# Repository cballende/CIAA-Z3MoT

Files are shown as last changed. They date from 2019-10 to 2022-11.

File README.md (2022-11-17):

# CIAA-Z3MoT
Simplificación de base board Silabs subGHz :
EZR32 Happy gecko board for QFP48 parts (EZR32HG)
[SLWSTK6244A](https://www.silabs.com/products/development-tools/wireless/proprietary/slwstk6244a-ezr32-happy-gecko-169-mhz-starter-kit)

| Kit | Frequency(MHz)| Output Power(dBm) |Included Device |
| --- |:---:| -----:|-----:|
| SLWSTK6244A | 169 | +20 | ZR32HG330FG63G |

#### Caracteristicas

* Adaptación de [CIAA-Z3R0](http://www.proyecto-ciaa.com.ar/devwiki/doku.php?id=desarrollo:ciaa-z3r0) hacia un enfoque de [MoTe](https://en.wikipedia.org/wiki/Sensor_node).

* Los pines entre Z3R0 y Z3MoT són compatibles en cierto grado, con excepción de los destinados a la interface RF.

* Puertos y pines deprecados de la versión Z3RO a la Z3MoT:
  - A:2,8,9,10. 
  - C:0,1,2,3,4. 

* Introduce 4 GPIO: 
Se utilizan 3 lineas para configurar puerto I2C para memoria EEPROM y posibles MEMs(disponibles V2.0,temperatura,humedad,7DOF,Altímetro-barómetro,luxómetro)

Deja un GPIO libre configurable sobre los restantes puertos:
- A:0,1.
- B:7,8,11,13,14.
- C:8,9,10,14,15.
- D:4,5,6,7.
- E:10,11,12,13.
- F:0,1,2,3,4.

* USB:
El conector usb se modifico, no se utiliza conector soldable. Se implemento un plug en pcb USB A troquelable, brindando la posiblidad soldar tira de pines de paso 1,27" o soldar en PCB tipo castellated.

* Alimentación:
Selección mediante jumper permitiendo conmutar bateria o (USB / PCBtarget).
La alimentación mediante bateria se implemento con fuente DC/DC tipo boost.

* Autonomía:
El stick Z3MoT tiene la posiblidad de usar baterias tipo boton CR2032(3V)(1,8 años autonomia 225 mAh) o mediante Pila AAA(7,25 años 1,5V de 900-1155 mAh). 

* Conectores RF:
Es posible utilizar dos tipos de conectores uno SMD(por defecto) y otro SMA(soldando via).

* JTAG:
Los pines utilizados en Z3RO son los mismos que para Z3MoT. Se adiciona tira de pines para conexión ordenada de JTAG  mediante sondas con resortes montadas sobre una pinza o base con balancin.
 

#### Schematic

[Schematic in pdf](ciaa-z3mot.pdf)
board schematic

#### 3D view

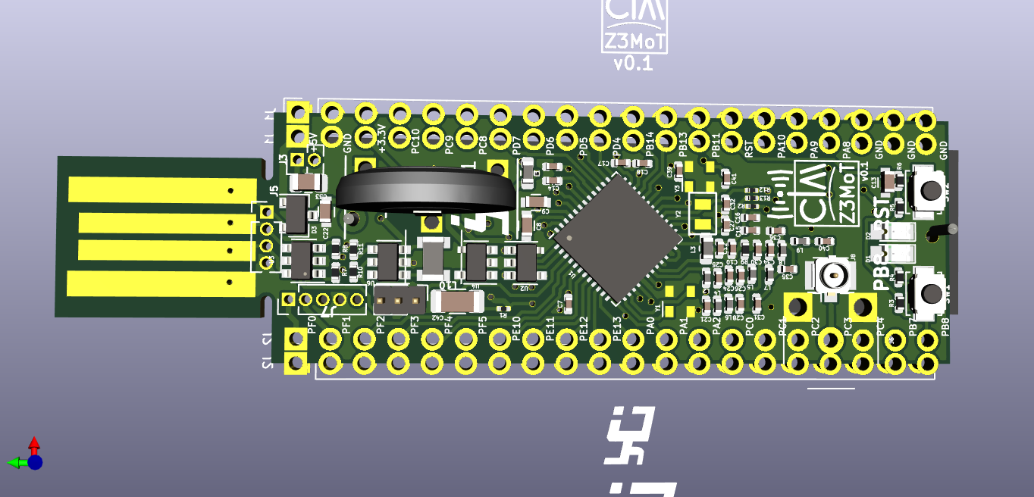
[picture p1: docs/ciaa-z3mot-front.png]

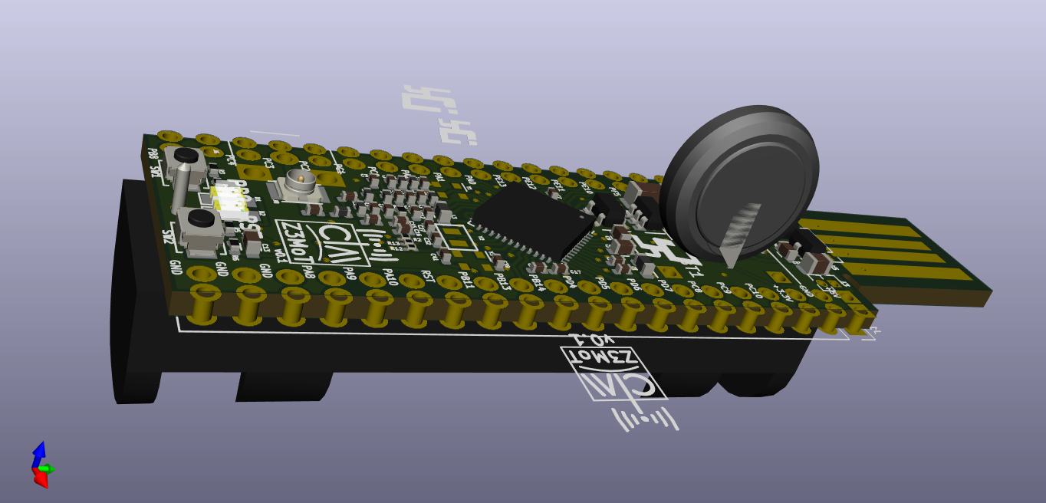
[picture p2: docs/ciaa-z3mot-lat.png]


## Vista con opciones de bateria y conector RF

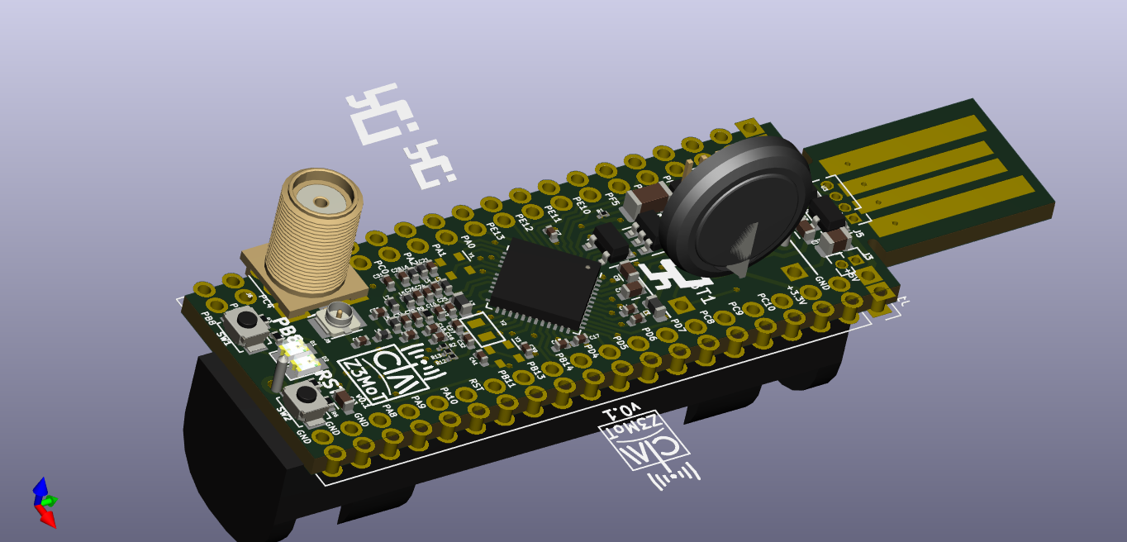
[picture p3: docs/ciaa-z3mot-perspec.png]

## Video (YOUTUBE)
Watch the video (https://youtu.be/JIxqX9fWDKY "Video CIAA-Z3MoT")

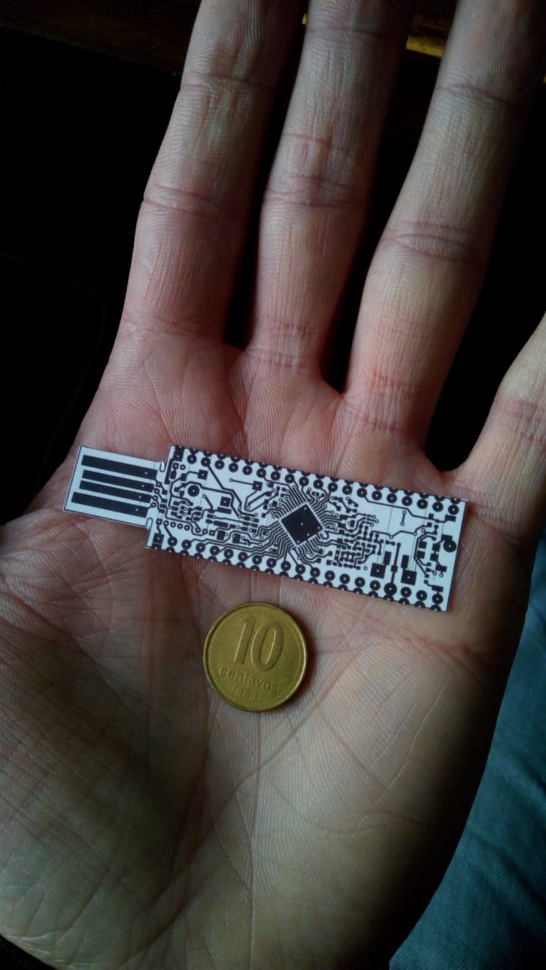
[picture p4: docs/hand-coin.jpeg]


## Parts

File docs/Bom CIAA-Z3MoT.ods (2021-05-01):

REFERENCIA | Qty. | Qty 100 | Qty 1000 | Qty 10000 | VALOR | HUELLA | DESCRIPCION | PART | digikey part number | ARROW | MOUSER | Pricing
BT1 | 1 | 100 | 1000 | 10000 | Battery_Cell | Battery holder CR2032-VS1N_Vertical_CircularHoles |  |  | 1
 |  | 0 | 0 | 0
C7 | 1 | 100 | 1000 | 10000 | 100n | Capacitor_SMD:C_0402_1005Metric |  | CC0402KRX7R7BB104 | 311-1088-1-ND |  | 603-CC603KRX7R7BB104
C8 | 1 | 100 | 1000 | 10000 | 1u | Capacitor_SMD:C_0603_1608Metric | Taiyo Yuden / Samsung | JMK107B7105KA-T / CL10B105KQ8NNNC | 1276-1024-1-ND |  | 963-JMK107B7105KA-T
C9 | 1 | 100 | 1000 | 10000 | 4,7u | Capacitor_SMD:C_0603_1608Metric | Taiyo Yuden | JMK107BB7475KA-T | 587-5870-1-ND |  | 963-JMK107BB7475KA-T
C10 | 1 | 100 | 1000 | 10000 | 100p | Capacitor_SMD:C_0402_1005Metric |  | CC0402JRNPO8BN101 | 311-3597-1-ND |  | 603-CC402JRNPO8BN101
C11 | 1 | 100 | 1000 | 10000 | 100n | Capacitor_SMD:C_0402_1005Metric |  | CC0402KRX7R7BB104 | 311-1088-1-ND |  | 603-CC603KRX7R7BB104
C12 | 1 | 100 | 1000 | 10000 | 470p | Capacitor_SMD:C_0402_1005Metric |  | CC0402JRNPO7BN471 | 311-1362-1-ND |  | 603-CC402JRNPO7BN471
C13 | 1 | 100 | 1000 | 10000 | 1u | Capacitor_SMD:C_0603_1608Metric |  | JMK107B7105KA-T | 311-1446-1-ND |  | 603-CC603KRX7R7BB105
C14 | 1 | 100 | 1000 | 10000 | 1u | Capacitor_SMD:C_0603_1608Metric | Taiyo Yuden / Samsung | JMK107B7105KA-T / CL10B105KQ8NNNC | 1276-1024-1-ND |  | 963-JMK107B7105KA-T
C15 | 1 | 100 | 1000 | 10000 | 100n | Capacitor_SMD:C_0402_1005Metric |  | CC0402KRX7R7BB104 | 311-1088-1-ND |  | 603-CC603KRX7R7BB104
C16 | 1 | 100 | 1000 | 10000 | 1u | Capacitor_SMD:C_0603_1608Metric | Taiyo Yuden / Samsung | JMK107B7105KA-T / CL10B105KQ8NNNC | 1276-1024-1-ND |  | 963-JMK107B7105KA-T
C17 | 1 | 100 | 1000 | 10000 | 100n | Capacitor_SMD:C_0402_1005Metric |  | CC0402KRX7R7BB104 | 311-1088-1-ND |  | 603-CC603KRX7R7BB104
C18 | 1 | 100 | 1000 | 10000 | 100n | Capacitor_SMD:C_0402_1005Metric |  | CC0402KRX7R7BB104 | 311-1088-1-ND |  | 603-CC603KRX7R7BB104
C42 | 1 | 100 | 1000 | 10000 | 10u | Capacitor_SMD:C_1206_3216Metric | Taiyo Yuden | JMK316BJ106KL-T | 587-5873-1-ND |  | 963-JMK316BJ106KL-T
C21 | 1 | 100 | 1000 | 10000 | 12p | Capacitor_SMD:C_0402_1005Metric |  | CC0402JRNPO9BN120 | 311-1016-1-ND |  | 603-CC402JRNPO9BN120
C22 | 1 | 100 | 1000 | 10000 | 1u | Capacitor_SMD:C_0603_1608Metric | Taiyo Yuden / Samsung | JMK107B7105KA-T / CL10B105KQ8NNNC | 1276-1024-1-ND |  | 963-JMK107B7105KA-T
C24 | 1 | 100 | 1000 | 10000 | 470p | Capacitor_SMD:C_0402_1005Metric |  | CC0402JRNPO7BN471 | 311-1362-1-ND |  | 603-CC402JRNPO7BN471
C25 | 1 | 100 | 1000 | 10000 | 6,2p | Capacitor_SMD:C_0402_1005Metric | KEMET | CBR04C629B5GAC | 399-16105-1-ND |  | 80-CBR04C629B5G
C26 | 1 | 100 | 1000 | 10000 | 11p | Capacitor_SMD:C_0402_1005Metric | KEMET | CBR04C110J5GAC | 399-8818-1-ND |  | 603-CC603KRX7R7BB104
C36 | 1 | 100 | 1000 | 10000 | 12p | Capacitor_SMD:C_0402_1005Metric |  | CBR04C120J5GAC | 399-6169-1-ND
C28 | 1 | 100 | 1000 | 10000 | NM | Capacitor_SMD:C_0402_1005Metric
C30 | 1 | 100 | 1000 | 10000 | 18p | Capacitor_SMD:C_0402_1005Metric | Yageo | CC0402JRNPO9BN180 | 311-1415-1-ND |  | 603-CC402JRNPO9BN180
C31 | 1 | 100 | 1000 | 10000 | 3p | Capacitor_SMD:C_0402_1005Metric | Yageo | CC0402CRNPO9BN3R0 | 311-1007-2-ND |  | 603-CC402CRNPO9BN3R0
C32 | 1 | 100 | 1000 | 10000 | 12p | Capacitor_SMD:C_0402_1005Metric |  | CBR04C120J5GAC | 399-6169-1-ND
C33 | 1 | 100 | 1000 | 10000 | 4,7u | Capacitor_SMD:C_0805_Metric | Walsin | 0805B475K6R3CT |  |  | 791-0805B475K6R3CT
C34 | 1 | 100 | 1000 | 10000 | 18p | Capacitor_SMD:C_0402_1005Metric | Yageo | CC0402JRNPO9BN180 | 311-1415-1-ND |  | 603-CC402JRNPO9BN180
C35 | 1 | 100 | 1000 | 10000 | 2p | Capacitor_SMD:C_0402_1005Metric | Yageo | CC0402CRNPO9BN2R0 | 311-1006-1-ND |  | 603-CC402CRNPO9BN2R0
C36 | 1 | 100 | 1000 | 10000 | 11p | Capacitor_SMD:C_0402_1005Metric | Samsung | CL05C110JB5NNNC | 1276-1637-1-ND | CL05C110JB5NNNC
C39 | 1 | 100 | 1000 | 10000 | 10p | Capacitor_SMD:C_0402_1005Metric |  | CBR04C100J5GAC | 399-6168-1-ND
C40 | 1 | 100 | 1000 | 10000 | 470p | Capacitor_SMD:C_0402_1005Metric |  | CC0402JRNPO7BN471 | 311-1362-1-ND |  | 603-CC402JRNPO7BN471
C41 | 1 | 100 | 1000 | 10000 | 10p | Capacitor_SMD:C_0402_1005Metric |  | CBR04C100J5GAC | 399-6168-1-ND
 |  | 0 | 0 | 0
D1 | 1 | 100 | 1000 | 10000 | PA8 | LED_0805 |  | LTST-C170GKT | 160-1179-1-ND
D2 | 1 | 100 | 1000 | 10000 | PWR | LED_0805 |  | LTST-C170GKT | 160-1179-1-ND
D3 | 1 | 100 | 1000 | 10000 | PMEG2005CT | SOT-23-3 |  | PMEG2005CT,215 | 1727-5188-1-ND
 |  | 0 | 0 | 0
J1, J2 |  | 0 | 0 | 0 | NM
J3 | 1 | 100 | 1000 | 10000 | JTAG | PinHeader_1x05_P1.27mm_Vertical
J4 | 1 | 100 | 1000 | 10000 | ON | PinHeader_1x02_P1.27mm_Vertical
J5 | 1 | 100 | 1000 | 10000 | SWD | PinHeader_1x03_P1.27mm_Vertical
J6 | 1 | 100 | 1000 | 10000 | USB | PinHeader_1x04_P1.27mm_Vertical
J7 | 1 | 100 | 1000 | 10000 | Conn_Coaxial | Connector_Coaxial:U.FL_Hirose_U.FL-R-SMT-1_Vertical |  | IPX U.FL RF
J8 | 1 | 100 | 1000 | 10000 | Conn_Coaxial | Connector_Coaxial:SMA_Amphenol_132134-16_Vertical
 |  | 0 | 0 | 0
L1 | 1 | 100 | 1000 | 10000 | Choque | Inductor_SMD:L_0402_1005Metric | Murata Electronics | BLM15AG121SN1D | 490-1005-1-ND |  | 81-BLM15AG121SN1D
L2 | 1 | 100 | 1000 | 10000 | 220 nH | Inductor_SMD:L_0402_1005Metric | Murata Electronics | LQW15CNR22J10D | 490-14717-1-ND |  | 81-LQW15CNR22J10D
L3 | 1 | 100 | 1000 | 10000 | 390 nH | Inductor_SMD:L_0603_1608Metric | Würth Elektronik | 744761239A | 732-744761239ACT-ND |  | 710-744761239A
L4 | 1 | 100 | 1000 | 10000 | 160nH | Inductor_SMD:L_0402_1005Metric | Murata Electronics | LQW15CNR16J00D | 490-14716-1-ND |  | 81-LQW15CNR16J00D0D
L5 | 1 | 100 | 1000 | 10000 | 82nH | Inductor_SMD:L_0402_1005Metric | Murata Electronics | LQW15AW82NJ80D |  |  | 81-LQW15AW82NJ80D
L6 | 1 | 100 | 1000 | 10000 | 47nH | Inductor_SMD:L_0402_1005Metric | Murata Electronics | LQW15AN47NJ80D |  |  | 81-LQW15AN47NJ80D
L8 | 1 | 100 | 1000 | 10000 | 47nH | Inductor_SMD:L_0402_1005Metric | Murata Electronics | LQW15AN47NJ80D |  |  | 81-LQW15AN47NJ80D
L7 | 1 | 100 | 1000 | 10000 | 68nH | Inductor_SMD:L_0402_1005Metric | Murata Electronics | LQW15AW68NJ80D |  |  | 81-LQW15AW68NJ80D
L9 | 1 | 100 | 1000 | 10000 | 27nH | Inductor_SMD:L_0402_1005Metric | Murata Electronics | LQW15AN27NJ8ZD | 490-15374-1-ND |  | 81-LQW15AN27NJ8ZD
L10 | 1 | 100 | 1000 | 10000 | 4,7uH | Inductor_SMD:L_-1008 (2520 Metric) | Murata Electronics | LQH2HPN4R7MJRL | 490-9904-1-ND |  | 81-LQH2HPN4R7MJRL
 |  | 0 | 0 | 0
R1, R2, | 2 | 200 | 2000 | 20000 | 1R | Resistor_SMD:R_0201_0603Metric | yageo | RC0201JR-071RL |  |  | 603-RC0201JR-071RL
R12-R13 | 2 | 200 | 2000 | 20000 | 0R | Resistor_SMD:R_0201_0603Metric | Vishay / Dale | CRCW02010000Z0ED | P15979CT-ND |  | 71-CRCW02010000Z0ED
R3-R4-R5-R6 | 4 | 400 | 4000 | 40000 | 1K | Resistor_SMD:R_0402_1005Metric | yageo | RC0402JR-071KL | 311-1.0KJRTR-ND
R7, R8 | 2 | 200 | 2000 | 20000 | 15R | Resistor_SMD:R_0402_1005Metric | yageo | RC0402JR-0715RL | 311-15JRCT-ND
R9 | 1 | 100 | 1000 | 10000 | 50 | Resistor_SMD:R_0402_1005Metric | yageo | RC0402FR-0749R9L | 311-49.9LRCT-ND
R11 | 1 | 100 | 1000 | 10000 | 562K | Resistor_SMD:R_0402_1005Metric | yageo | RC0402FR-07562KL | 311-562KLRCT-ND
R10 | 1 | 100 | 1000 | 10000 | 976K | Resistor_SMD:R_0402_1005Metric | yageo | RC0402FR-07976KL | YAG3265CT-ND
> SW1, SW2 | 2 | 200 | 2000 | 20000 | reset | Button_Switch_SMD: B3U-1000P 1.70 X 3 X2.5 mm |  | B3U-1000P
 |  | 0 | 0 | 0
U1 | 1 | 100 | 1000 | 10000 | EZM32HG320-48QFN | QFN-48-1EP_7x7mm_P0.5mm_EP5.3x5.3mm | Silabs | EZR32HG320F64R68G | 336-3677-ND | EZR32HG320F64R68G-B0 | EZR32HG320F64R68G-B0 | $4.60
U2 | 1 | 100 | 1000 | 10000 | 24AA02E48-OT | SOT-23-5 |  | 24AA02E48T-I/OT | 24AA02E48T-I/OTCT-ND
U3 | 1 | 100 | 1000 | 10000 | USBLC6-2 | SOT-23-6 |  | USBLC6-2SC6 | 497-5235-1-ND
U4 | 1 | 100 | 1000 | 10000 | SPX3819M5-L-3-3 | SOT-23-5 |  | SPX3819M5-L-3-3/TR | 1016-1873-1-ND
U5 | 1 | 100 | 1000 | 10000 | USB_PCB_PRINT | USB_PCB_FOOTPRINT
U6 | 1 | 100 | 1000 | 10000 | MCP1640C | SOT-23-6 | MICROCHIP | MCP1640CT-I/CHY | MCP1640CT-I/CHYCT-ND
 |  | 0 | 0 | 0
Y1 | 1 | 100 | 1000 | 10000 | 30MHz | Oscillator:Oscillator_SMD_Abracon_ASDMB-4Pin_2x1,6mm | Abracon LLC | ABM11-30.000MHZ-B1U-T | 535-14960-1-ND
Y2 | 1 | 100 | 1000 | 10000 | 32.1KHz | footprints:Xtal_LF | Abracon LLC | ABS06-32.768KHZ-1-T | 535-10248-1-ND |  | 815-ABS06-32.7K-1-T
Y3 | 1 | 100 | 1000 | 10000 | 24MHz | Oscillator:Oscillator_SMD_Abracon_ASDMB-4Pin_2x1,6mm | Murata Electronics | XRCGB24M000F1H01R0 | 490-18288-1-ND

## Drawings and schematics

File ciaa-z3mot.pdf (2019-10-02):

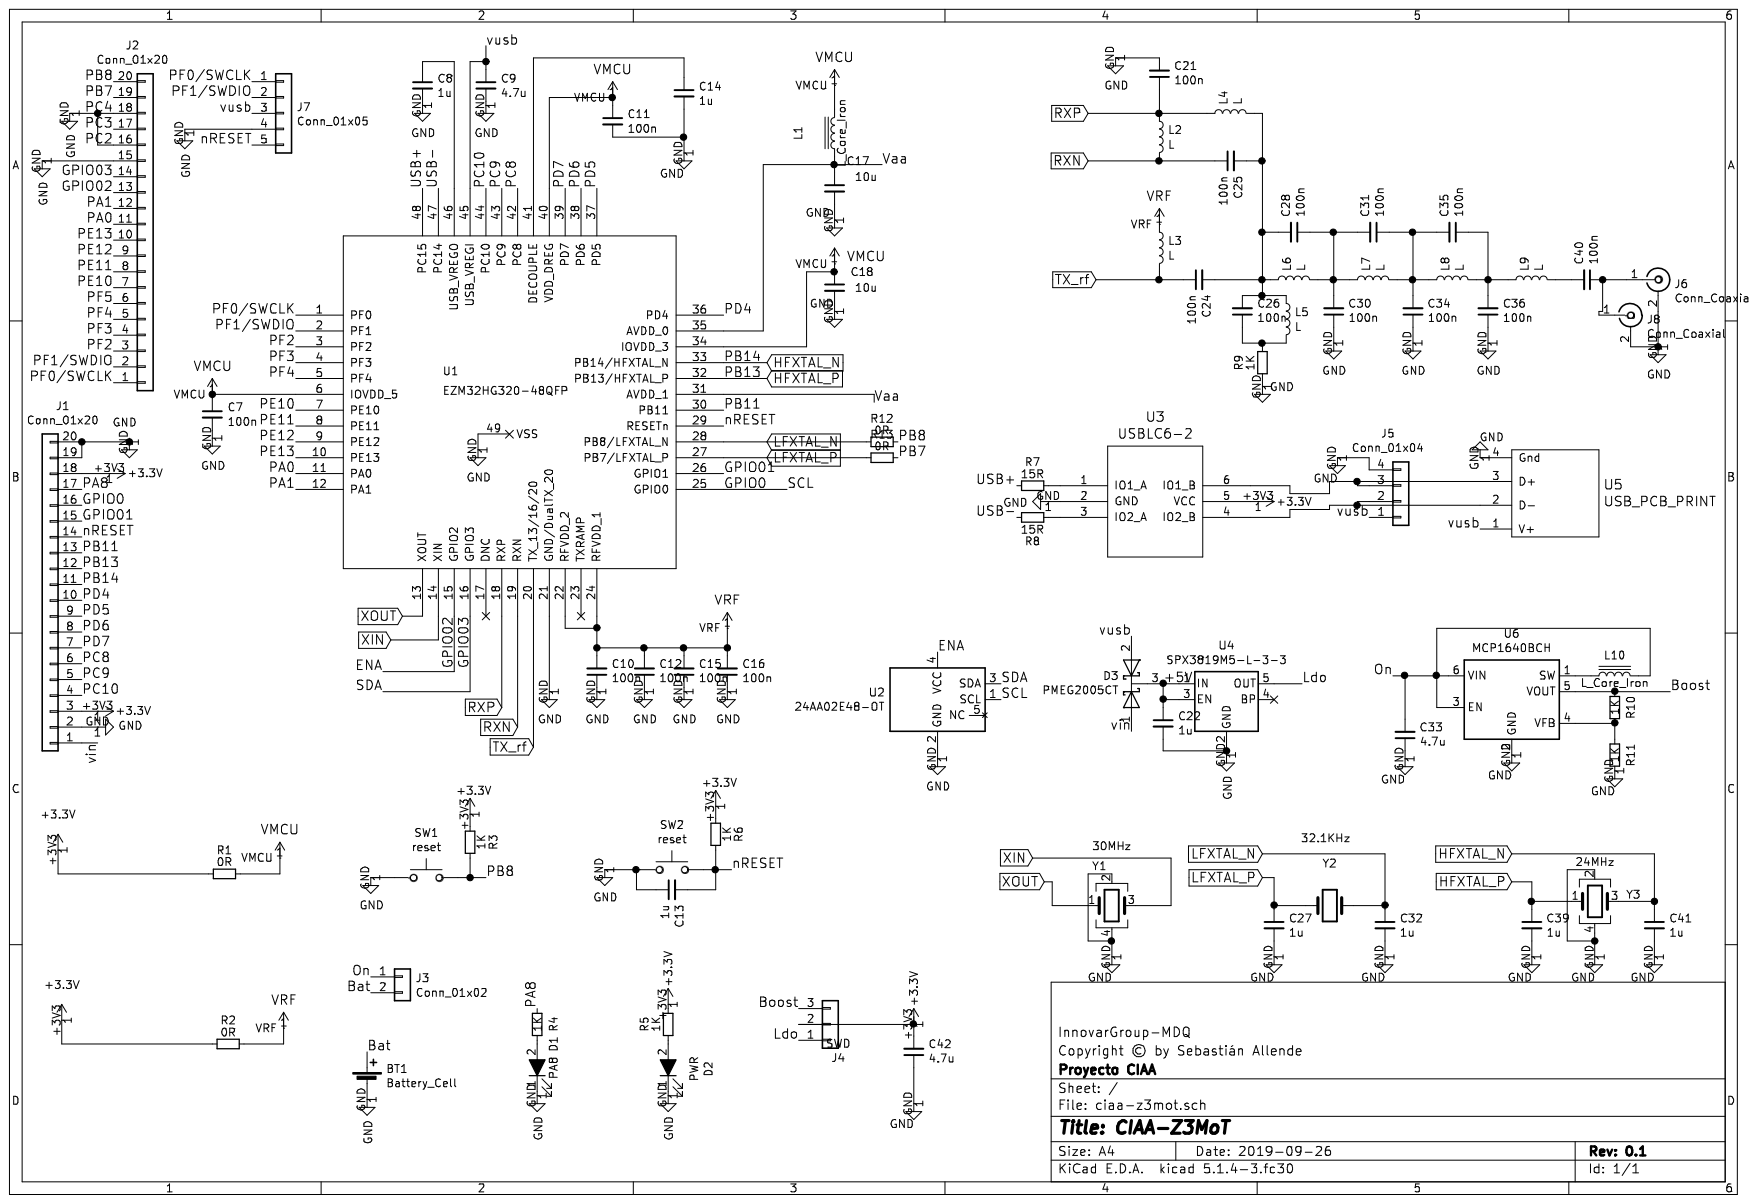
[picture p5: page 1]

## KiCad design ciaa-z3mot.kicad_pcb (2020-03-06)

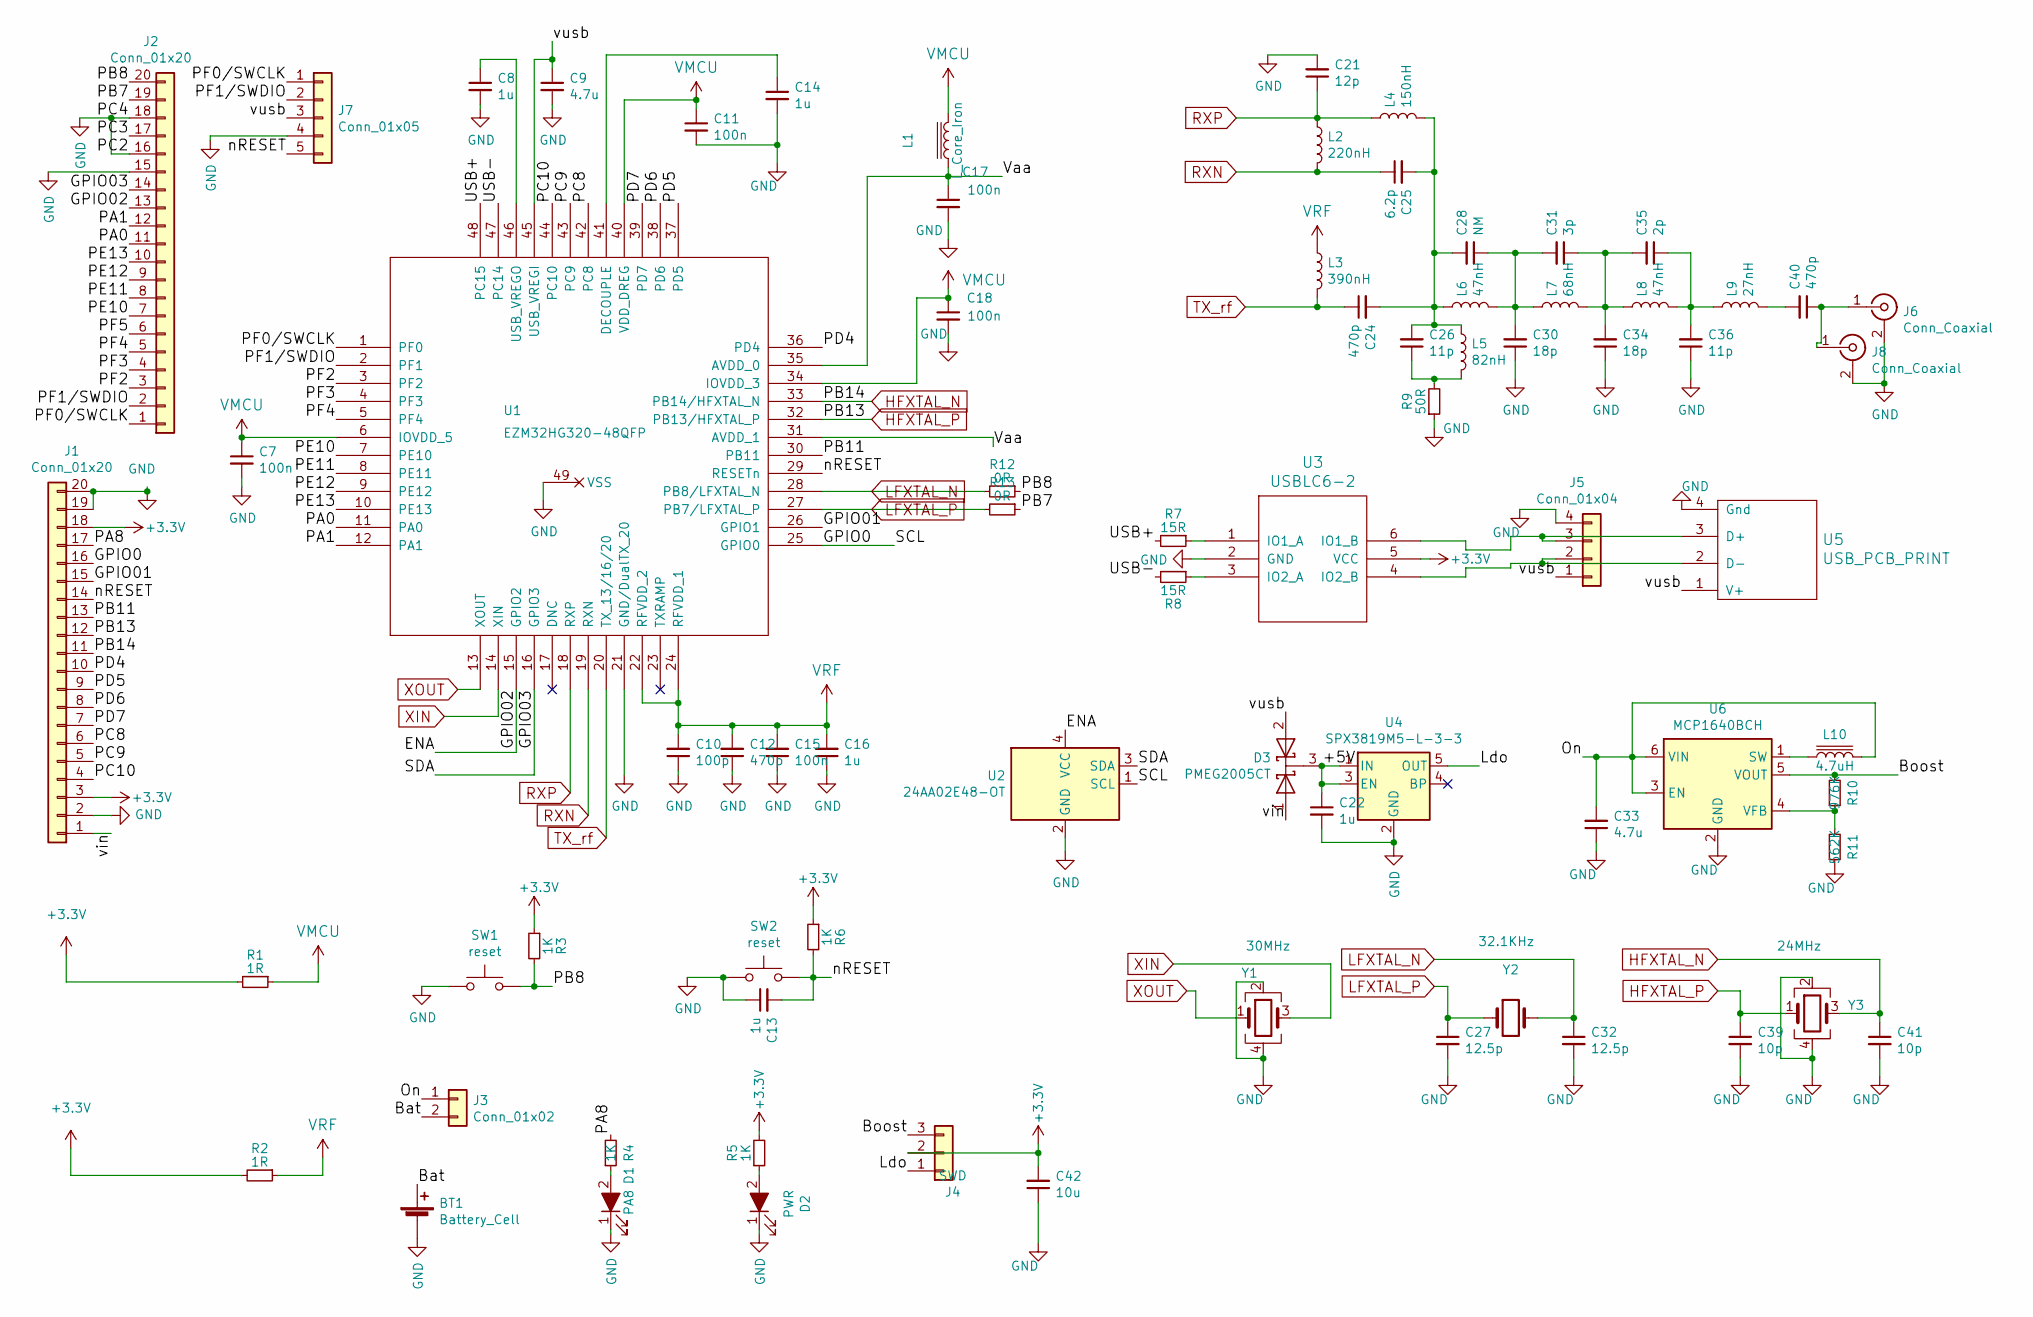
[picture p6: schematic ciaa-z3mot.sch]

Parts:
BT1: Battery_Cell; Battery_Panasonic_CR2032-VS1N_Vertical_CircularHoles
C7, C11, C15, C17, C18: 100n; C_0402_1005Metric
C8, C13, C22: 1u; C_0603_1608Metric
C9: 4.7u; C_0603_1608Metric
C10: 100p; C_0402_1005Metric
C12, C24, C40: 470p; C_0402_1005Metric
C14, C16: 1u; C_0402_1005Metric
C21: 12p; C_0402_1005Metric
C25: 6.2p; C_0402_1005Metric
C26, C36: 11p; C_0402_1005Metric
C27, C32: 12.5p; C_0402_1005Metric
C28: NM; C_0402_1005Metric
C30, C34: 18p; C_0402_1005Metric
C31: 3p; C_0402_1005Metric
C33: 4.7u; C_0805_2012Metric
C35: 2p; C_0402_1005Metric
C39, C41: 10p; C_0402_1005Metric
C42: 10u; C_1206_3216Metric
D1: PA8; LED_0805
D2: PWR; LED_0805
D3: PMEG2005CT; SOT-23
J1, J2: Conn_01x20; Pin_Header_Straight_1x20_Pitch2.54mm
J3: Conn_01x02; PinHeader_1x02_P1.27mm_Vertical
J4: SWD; PinHeader_1x03_P1.27mm_Vertical
J5: Conn_01x04; PinHeader_1x04_P1.27mm_Vertical
J6: Conn_Coaxial; SMA_Amphenol_132134-16_Vertical
J7: Conn_01x05; PinHeader_1x05_P1.27mm_Vertical
J8: Conn_Coaxial; U.FL_Hirose_U.FL-R-SMT-1_Vertical
L1: L_Core_Iron; L_0402_1005Metric
L2: 220nH; L_0402_1005Metric
L3: 390nH; L_0603_1608Metric
L4: 150nH; L_0402_1005Metric
L5: 82nH; L_0402_1005Metric
L6, L8: 47nH; L_0402_1005Metric
L7: 68nH; L_0402_1005Metric
L9: 27nH; L_0402_1005Metric
L10: 4.7uH; L_1008_2520Metric
R1, R2: 1R; R_0201_0603Metric
R3, R4, R5, R6: 1K; R_0402_1005Metric
R7, R8: 15R; R_0402_1005Metric
R9: 50R; R_0402_1005Metric
R10: 976K; R_0402_1005Metric
R11: 562K; R_0402_1005Metric
R12, R13: 0R; R_0201_0603Metric
SW1, SW2: reset; SW_SPST_B3U-1000P
U1: EZM32HG320-48QFP; QFN-48-1EP_7x7mm_P0.5mm_EP5.3x5.3mm
U2: 24AA02E48-OT; SOT-23-5
U3: USBLC6-2; SOT-23-6
U4: SPX3819M5-L-3-3; SOT-23-5
U5: USB_PCB_PRINT; USB_PCB_FOOTPRINT
U6: MCP1640BCH; SOT-23-6
Y1: 30MHz; Oscillator_SMD_Abracon_ASDMB-4Pin_2.5x2.0mm
Y2: 32.1KHz; Xtal_LF
Y3: 24MHz; Oscillator_SMD_Abracon_ASDMB-4Pin_2.5x2.0mm

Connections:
+3V3: C42.2, J1.3, J1.18, J4.2, R1.2, R2.2, R3.1, R5.2, R6.1, U3.5 (VCC); also elsewhere on the board
/+5V: C22.1, D3.3 (K), U4.1 (IN), U4.3 (EN)
/Bat: BT1.1 (+), J3.2
/Boost: J4.3, R10.2, U6.5 (VOUT)
/ENA: J2.13, U1.15 (GPIO2), U2.4 (VCC); also elsewhere on the board
/GPIO0: J1.16, U1.25 (GPIO0), U2.1 (SCL); also elsewhere on the board
/GPIO01: J1.15, U1.26 (GPIO1); also elsewhere on the board
/GPIO03: J2.14, U1.16 (GPIO3), U2.3 (SDA); also elsewhere on the board
/Ldo: J4.1, U4.5 (OUT)
/On: C33.2, J3.1, L10.2, U6.3 (EN), U6.6 (VIN)
/PA0: J2.11, U1.11 (PA0); also elsewhere on the board
/PA1: J2.12, U1.12 (PA1); also elsewhere on the board
/PA8: J1.17, R4.2; also elsewhere on the board
/PB7: J2.19, R13.1; also elsewhere on the board
/PB8: J2.20, R3.2, R12.1, SW1.2; also elsewhere on the board
/PB11: J1.13, U1.30 (PB11); also elsewhere on the board
/PC3: J2.17; also elsewhere on the board
/PC8: J1.6, U1.42 (PC8); also elsewhere on the board
/PC9: J1.5, U1.43 (PC9); also elsewhere on the board
/PC10: J1.4, U1.44 (PC10); also elsewhere on the board
/PD4: J1.10, U1.36 (PD4); also elsewhere on the board
/PD5: J1.9, U1.37 (PD5); also elsewhere on the board
/PD6: J1.8, U1.38 (PD6); also elsewhere on the board
/PD7: J1.7, U1.39 (PD7); also elsewhere on the board
/PE10: J2.7, U1.7 (PE10); also elsewhere on the board
/PE11: J2.8, U1.8 (PE11); also elsewhere on the board
/PE12: J2.9, U1.9 (PE12); also elsewhere on the board
/PE13: J2.10, U1.10 (PE13); also elsewhere on the board
/PF0/SWCLK: J2.1, J7.1, U1.1 (PF0); also elsewhere on the board
/PF1/SWDIO: J2.2, J7.2, U1.2 (PF1); also elsewhere on the board
/PF2: J2.3, U1.3 (PF2); also elsewhere on the board
/PF3: J2.4, U1.4 (PF3); also elsewhere on the board
/PF4: J2.5, U1.5 (PF4); also elsewhere on the board
/PF5: J2.6; also elsewhere on the board
/USB+: R7.2, U1.48 (PC15)
/USB-: R8.2, U1.47 (PC14)
/Vaa: C17.1, L1.1, U1.31 (AVDD_1), U1.35 (AVDD_0)
/nRESET: C13.2, J1.14, J7.5, R6.2, SW2.2, U1.29 (RESETn); also elsewhere on the board
/vin: D3.1 (A), J1.1; also elsewhere on the board
/vusb: C9.1, D3.2 (A), J5.1, J7.3, U1.45 (USB_VREGI), U5.1 (V+)
GND: BT1.2 (-), C7.2, C8.2, C9.2, C10.1, C11.2, C12.1, C13.1, C14.2, C15.1, C16.1, C17.2, C18.2, C21.2, C22.2, C27.2, C30.1, C32.2, C33.1, C34.1, C36.1, C39.2, C41.2, C42.1, D1.1 (K), D2.1 (K), J1.2, J1.19, J1.20, J2.15, J2.16, J2.18, J5.4, J6.2 (Ext), J7.4, J8.2 (Ext), R9.1, R11.1, SW1.1, SW2.1, U1.21 (GND/DualTX_20), U1.49 (VSS), U2.2 (GND), U3.2 (GND), U4.2 (GND), U5.4 (Gnd), U6.2 (GND), Y1.2, Y1.4, Y3.2, Y3.4; also elsewhere on the board
HFXTAL_N: C41.1, J1.11, U1.33 (PB14/HFXTAL_N), Y3.3; also elsewhere on the board
HFXTAL_P: C39.1, J1.12, U1.32 (PB13/HFXTAL_P), Y3.1; also elsewhere on the board
LFXTAL_N: C32.1, R12.2, U1.28 (PB8/LFXTAL_N), Y2.2
LFXTAL_P: C27.1, R13.2, U1.27 (PB7/LFXTAL_P), Y2.1
unnamed: C8.1, U1.46 (USB_VREGO)
unnamed: C14.1, U1.41 (DECOUPLE)
unnamed: C24.2, C25.2, C26.2, C28.2, L4.2, L5.1, L6.1
unnamed: C26.1, L5.2, R9.2
unnamed: C28.1, C30.2, C31.2, L6.2, L7.1
unnamed: C31.1, C34.2, C35.2, L7.2, L8.1
unnamed: C35.1, C36.2, L8.2, L9.1
unnamed: C40.1, J6.1 (In), J8.1 (In)
unnamed: C40.2, L9.2
unnamed: D1.2 (A), R4.1
unnamed: D2.2 (A), R5.1
unnamed: J5.2, U3.4 (IO2_B), U5.2 (D-)
unnamed: J5.3, U3.6 (IO1_B), U5.3 (D+)
unnamed: L10.1, U6.1 (SW)
unnamed: R7.1, U3.1 (IO1_A)
unnamed: R8.1, U3.3 (IO2_A)
unnamed: R10.1, R11.2, U6.4 (VFB)
RXN: C25.1, L2.2, U1.19 (RXN)
RXP: C21.1, L2.1, L4.1, U1.18 (RXP)
TX_rf: C24.1, L3.2, U1.20 (TX_13/16/20)
VMCU: C7.1, C11.1, C18.1, L1.2, R1.1, U1.6 (IOVDD_5), U1.34 (IOVDD_3), U1.40 (VDD_DREG)
VRF: C10.2, C12.2, C15.2, C16.2, L3.1, R2.1, U1.22 (RFVDD_2), U1.24 (RFVDD_1)
XIN: U1.14 (XIN), Y1.3
XOUT: U1.13 (XOUT), Y1.1

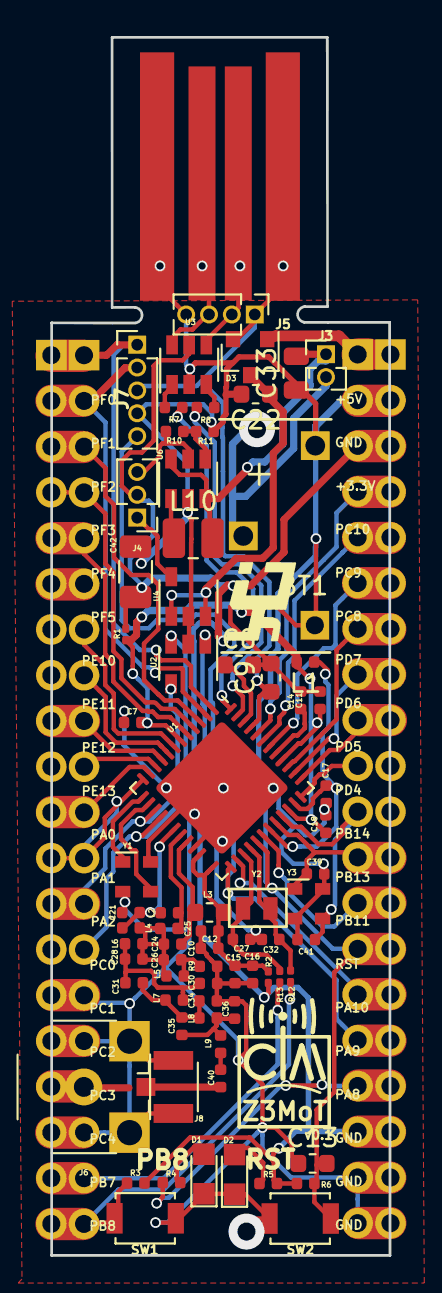
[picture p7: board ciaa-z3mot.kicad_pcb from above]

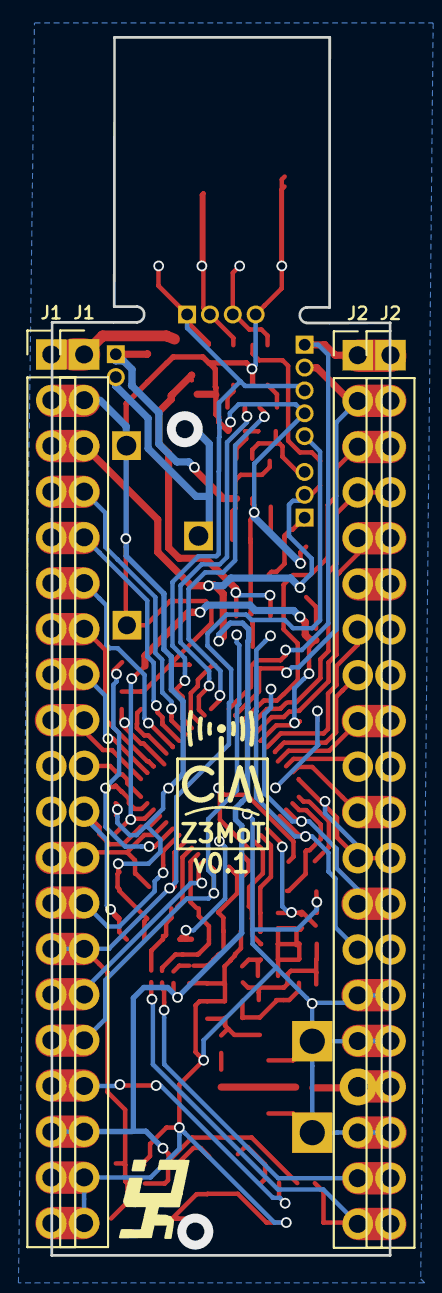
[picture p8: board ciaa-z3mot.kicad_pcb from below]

Board: 2 copper layers, 18.8 x 67.7 mm, 78 parts (4 on the bottom side), 69 nets.

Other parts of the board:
J1#2, J2#2: Conn_01x20; Pin_Header_Straight_1x20_Pitch2.54mm

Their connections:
+3V3: J1#2.3, J1#2.18; also elsewhere on the board
/ENA: J2#2.13; also elsewhere on the board
/GPIO0: J1#2.16; also elsewhere on the board
/GPIO01: J1#2.15; also elsewhere on the board
/GPIO03: J2#2.14; also elsewhere on the board
/PA0: J2#2.11; also elsewhere on the board
/PA1: J2#2.12; also elsewhere on the board
/PA8: J1#2.17; also elsewhere on the board
/PB7: J2#2.19; also elsewhere on the board
/PB8: J2#2.20; also elsewhere on the board
/PB11: J1#2.13; also elsewhere on the board
/PC3: J2#2.17; also elsewhere on the board
/PC8: J1#2.6; also elsewhere on the board
/PC9: J1#2.5; also elsewhere on the board
/PC10: J1#2.4; also elsewhere on the board
/PD4: J1#2.10; also elsewhere on the board
/PD5: J1#2.9; also elsewhere on the board
/PD6: J1#2.8; also elsewhere on the board
/PD7: J1#2.7; also elsewhere on the board
/PE10: J2#2.7; also elsewhere on the board
/PE11: J2#2.8; also elsewhere on the board
/PE12: J2#2.9; also elsewhere on the board
/PE13: J2#2.10; also elsewhere on the board
/PF0/SWCLK: J2#2.1; also elsewhere on the board
/PF1/SWDIO: J2#2.2; also elsewhere on the board
/PF2: J2#2.3; also elsewhere on the board
/PF3: J2#2.4; also elsewhere on the board
/PF4: J2#2.5; also elsewhere on the board
/PF5: J2#2.6; also elsewhere on the board
/nRESET: J1#2.14; also elsewhere on the board
/vin: J1#2.1; also elsewhere on the board
GND: J1#2.2, J1#2.19, J1#2.20, J2#2.15, J2#2.16, J2#2.18; also elsewhere on the board
HFXTAL_N: J1#2.11; also elsewhere on the board
HFXTAL_P: J1#2.12; also elsewhere on the board

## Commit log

2019-10-01 mejoras 1
    [ciaa-z3mot.kicad_pcb, ciaa-z3mot.sch]
2019-10-02 sin verificar ruteo gnd
    [ciaa-z3mot.kicad_pcb, ciaa-z3mot.sch]
2019-10-03 render completo y cambio smd pack
    [ciaa-z3mot.kicad_pcb, ciaa-z3mot.sch]
2019-10-03 agrego porta baterias
    [ciaa-z3mot.kicad_pcb]
2019-10-03 implementación con opciones
    [ciaa-z3mot.kicad_pcb]
2019-10-04 Edición readme
    [ciaa-z3mot.kicad_pcb]
2019-10-04 more readme!!! ):
    [ciaa-z3mot.kicad_pcb]
2020-03-06 BOM
    edicion de fb mdp1640 y en el bom
    [Bom CIAA-Z3MoT.ods, bom_v0.1.xls, bom_v0.2.xls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]

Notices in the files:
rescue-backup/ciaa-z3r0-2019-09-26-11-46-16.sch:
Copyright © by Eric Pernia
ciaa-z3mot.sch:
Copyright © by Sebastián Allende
